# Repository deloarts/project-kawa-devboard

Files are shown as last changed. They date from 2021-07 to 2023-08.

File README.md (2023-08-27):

# Project Kawa Devboard

Documentation for the **Project Kawa Devboard**. This repository contains everything the Wifi-Client requires, including code, circuit design and housing.
















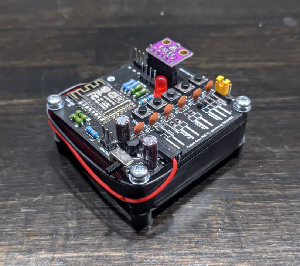
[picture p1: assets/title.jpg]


> ⚠️ The Kawa Devboard is part of my condition monitoring project - Project Kawa - which isn't public. However, this repo is public, because the development board itself works pretty well after a long-term test of now over a year. You can use this board for your own project, if it fits your needs.
> 
> ✏️ The board is compatible with most open source home-automation systems, so feel free to use this board for other appliances than the Project Kawa.
>
> ✏️ In this repo you'll find not only the hardware of the devboard, but also the source. Keep in mind that the code is written for the Project Kawa Server, which isn't public, but feel free to tweak it for your own application.

## Table of contents

- [Project Kawa Devboard](#project-kawa-devboard)
  - [Table of contents](#table-of-contents)
  - [1 Description](#1-description)
  - [2 Usage](#2-usage)
    - [2.1 LED indicator](#21-led-indicator)
    - [2.2 Setup wifi](#22-setup-wifi)
    - [2.3 Reading sensor data](#23-reading-sensor-data)
    - [2.4 Status codes](#24-status-codes)
  - [3 Hardware](#3-hardware)
    - [3.1 Board](#31-board)
    - [3.2 Housing](#32-housing)
  - [4 Environment](#4-environment)
    - [4.1 Used software](#41-used-software)
    - [4.2 VS-Code setup](#42-vs-code-setup)
      - [4.2.1 code-workspace](#421-code-workspace)
      - [4.2.2 arduino.json](#422-arduinojson)
      - [4.2.3 c\_cpp\_properties.json](#423-c_cpp_propertiesjson)
    - [4.3 Eagle libraries](#43-eagle-libraries)
  - [5 Building \& Debugging](#5-building--debugging)
    - [5.1 Initial upload](#51-initial-upload)
    - [5.2 OTA upload](#52-ota-upload)
    - [5.3 Build the firmware](#53-build-the-firmware)
    - [5.4 Build the filesystem](#54-build-the-filesystem)
    - [5.5 Debug](#55-debug)
  - [6 License \& Disclaimer](#6-license--disclaimer)
  - [7 Changelog](#7-changelog)
    - [7.1 Firmware](#71-firmware)
    - [7.2 Filesystem](#72-filesystem)
    - [7.3 PCB](#73-pcb)
    - [7.4 Housing](#74-housing)
  - [8 To Do](#8-to-do)

## 1 Description

**Project Kawa Devboard** is part of the **Project Kawa** environment. This client is designed to test new sensors or new firmware, to debug code or find optimizations in the PCB layout. The latest version may not work without properly -> nightly builds.

This repository contains mostly code that is in development, as well as hardware-design that might only work under special conditions or differ from this documentation. This is not an out-of-the-box solution and requires some knowledge in a variety of fields. If you don't have an education in the field of electronics you should not proceed with this project, you might harm yourself or create damage by the risk of fire. Further you should be comfortable working with VS Code Workspaces.

Please note: All paths and settings are described for Windows. Will be updated in the future.

## 2 Usage

**This requires a working build of the firmware and filesystem already flashed to the chip, see [Initial Upload](#51-initial-upload)**. Please note: The description can differ from the actual process, depending on the development state of this device.

### 2.1 LED indicator

There are different kinds of LED-states to indicate the device's status:

- Short, almost unnoticeable blink: Wakeup from deepsleep, running normal cycle
- Rapid blinking 25 times: Wifi is not setup (this should happen after the initial upload)
- Rapid blinking 2 times: Changes have been written to the config
- On-Off every one second: Wifi-setup is running, hotspot is open

### 2.2 Setup wifi

The device needs to connect to your local network via 2.4GHz wifi. To setup your network's credentials you need to

- press and hold **BUTTON 1**
- click the **RESET** button
- the device opens a hotspot called **kawa setup**
- connect any wifi-enabled device to it
- enter your network-credentials
- select the connected sensor
- select the sleep interval (shorter intervals should only be used for testing and debugging)
- reset the controller afterwards

Now your *Kawa Devboard* is ready for use. As soon as the device connects to your wifi it will automatically connect to the server by its own, assuming that the server is running.

Note: The captive portal may not work properly, if so try:

- Use another device
- Click **yes** if your device asks you to stay connected (happens when the device notices, that no internet connection is available)
- Refresh the captive portal redirection page (sometimes the script or the stylesheet aren't loaded properly)
- Enter the IP address **1.2.3.4** manually into a browser

### 2.3 Reading sensor data

Once the wifi credentials are set up correct the device starts its main task: reading sensor data. There is no further interaction needed. The data is sent as json, example:

```json
{
  "device": {
    "id": "179309432879183923",
    "boardname": "devboard",
    "firmware_version": "0.1.0",
    "filesystem_version": "0.1.0",
    "mode": "production",
    "sensor_status": true,
    "sensor_name": "BMP280",
    "battery_status": true,
    "battery_value": 3.30,
    "sleep_interval": 3600,
    "connection_time": 7.334,
    "ssid": "the_network_ssid",
    "dbm": -78,
    "quality": 44,
    "hostname": "kawa_179309432879183923",
    "ip_address": "192.168.0.200",
    "mac_address": "00:80:41:ae:fd:7e"
  },
  "data": {
    "temperature": {
      "value": 25.2,
      "unit": "°C"
    },
    "pressure": {
      "value": 989.2,
      "unit": "mBar"
    },
    "altitude": {
      "value": 433,
      "unit": "m"
    },
    "humidity": {
      "value": 44.23,
      "unit": "%"
    }
  }
}
```

The server must answer with status code 201 and a json of the following format:

```json
value = {
    "status": "ok",
    "update_firmware": false,
    "new_firmware": "0.0.0",
    "update_spiffs": false,
    "new_spiffs": "0.0.0"
}
```

Due to the OTA-update functionality the client must know when to update. This is done by toggling the respective keys to **true**. With this the client will instantly download the given new version. The maximum size of the json is 2048 bytes.

### 2.4 Status codes

The devices accepts the following status codes as answer when posting data:

- **201**: data has been added to the database
- **406**: data has not been added to the database
- **500**: server error

## 3 Hardware

The core of this application is a ESP12F SOC by [espressif](https://www.espressif.com/en/products/socs/esp8266).

### 3.1 Board

The board is a two layered pcb, with mostly push-through components. This is due to easier hacking into the system, when something new needs testing without making a new pcb.

A complete bill of material can be found inside the [bom folder](docs/bom/).
For the production files select the latest zip-file inside the boards folder.

**Important note**: There is no deep discharge protection for the battery. Do not use non-protected batteries with this setup!

### 3.2 Housing

The housing is made with a 3D printer, files can be found inside the projects cad folder. More information will be added.

## 4 Environment

### 4.1 Used software

- The firmware is created with [VS Code](https://code.visualstudio.com/download) with the [Arduino-Core](https://www.arduino.cc/en/software) (extension: CTRL+P -> *ext install vscode-arduino*))
- The content of the filesystem is compiled with [mkspiffs](https://github.com/igrr/mkspiffs) and uploaded with [esptool](https://github.com/espressif/esptool).
- The pcb design is done with [Autodesk Eagle 9.6.2](https://www.autodesk.de/products/eagle/free-download), but may be continued with [EasyEDA](https://easyeda.com/) due to a better library-to-production support.

A full list of the used software, including versions, libraries and tools can be found at the top of the [src.ino](code/src/src.ino).

### 4.2 VS-Code setup

#### 4.2.1 code-workspace

Workspace-root is the repository-root. All relative paths are from this directory. Add the repository-root to a new workspace and save this workspace (can be saved inside or outside of the repo).

#### 4.2.2 arduino.json

Stored inside the **.vscode/** folder. This folder does not exist when cloning the repo and should appear automatically after creating the workspace, if not:

- Create it: [command-palette](https://code.visualstudio.com/docs/getstarted/userinterface#_command-palette) -> *Arduino: Initialize*
- Edit it: [command-palette](https://code.visualstudio.com/docs/getstarted/userinterface#_command-palette) -> *Arduino: Board Config*

Take the current board config from the description at the top of the [src file](code/src/src.ino).

Add the following lines to the json-file:

```json
  "sketch": "code\\src\\src.ino",
  "output": "code\\build\\firmware\\latest",
```

For the Arduino-Board-Config see the header-comment of the src-file.

#### 4.2.3 c_cpp_properties.json

Stored inside the **.vscode/** folder, create (or add):

```json
"configurations": [
    {
        "name": "Win32",
        "intelliSenseMode": "gcc-x64",
        "includePath": [
            "${workspaceRoot}\\code\\src\\",
            "${workspaceRoot}\\code\\src\\headers\\**",
            "C:\\Program Files (x86)\\Arduino\\hardware\\arduino\\avr\\cores\\arduino\\**",
            "${env:LOCALAPPDATA}\\Arduino15\\packages\\esp8266\\tools\\**",
            "${env:LOCALAPPDATA}\\Arduino15\\packages\\esp8266\\hardware\\esp8266\\3.0.0\\**",
            "${env:LOCALAPPDATA}\\Arduino15\\packages\\esp8266\\hardware\\esp8266\\3.0.0\\libraries\\**",
            "${env:HOMEPATH}\\Documents\\Arduino\\libraries\\ArduinoJson\\**",
            "${env:HOMEPATH}\\Documents\\Arduino\\libraries\\DallasTemperature\\**",
            "${env:HOMEPATH}\\Documents\\Arduino\\libraries\\OneWire\\**",
            "${env:HOMEPATH}\\Documents\\Arduino\\libraries\\Adafruit_Unified_Sensor\\**",
            "${workspaceRoot}\\code\\assets\\libraries\\Adafruit_BME280_Library\\**"
        ],
        "forcedInclude": [
            "C:\\Program Files (x86)\\Arduino\\hardware\\arduino\\avr\\cores\\arduino\\Arduino.h"
        ],
        "cStandard": "c11",
        "cppStandard": "c++17",
        "defines": []
    }
]
```

Please note: Some include-paths are only valid if you have chosen the standard path when you installed the Arduino-IDE on a Windows computer.

### 4.3 Eagle libraries

Can be found inside the pcb-folder. Must not be added to EAGLE if you don't plan on changing the board.

## 5 Building & Debugging

Tested and released firmware and filesystem versions can be found inside the respective folder

- [Firmware](code/build/firmware/)
- [Filesystem](code/build/filesystem/)

Those firmware-versions with the letter **d** after the version indicator are debug-versions. This means that you can hookup a serial-to-usb chip and get debug messages printed to a serial monitor. Baud-rate is always 115200. Versions without that letter are for production environment, you won't get any messages printed to the serial port.

### 5.1 Initial upload

To flash the firmware and filesystem initially you need to upload both with a usb-to-serial converter (popular method: use a [FTDI232 module](https://ftdichip.com/drivers/)). The upload process requires you to

- press and hold the **UPLOAD** button
- press and release the **RESET** button
- release the **UPLOAD** button as soon as the upload begins
- click the **RESET** button after the upload is done

The initial firmware can be uploaded with the command-palette -> *Arduino: Upload*.

The initial filesystem can be uploaded with *[SPIFFS for Arduino](https://github.com/esp8266/arduino-esp8266fs-plugin/releases)*.

### 5.2 OTA upload

New firmware/filesystem will be automatically installed by the **Project Kawa Server**. With every post-request (device -> server) the server answers with the newest firmware/filesystem version. If the current one is older the device will download and install the latest one. This process is called OTA.

This requires a working initial firmware to be flashed onto the device, see [Initial Setup](#51-initial-upload).

In order for the OTA to work you then have to copy the newest firmware/filesystem into the server's bin-directory. Please refer to the server's documentation for the correct filename or use the [test server](code/dev/test_server/test_server.py) from the **/dev** folder. The test server returns only the file set at the top-section. Do not use the test server in a production environment.

### 5.3 Build the firmware

The firmware is built when the src-file is compiled without any errors (command-palette -> *Arduino: Verify*). The binary file is then stored inside the latest-folder of build-directory, as instructed in the *4.2.2 arduino.json*.

### 5.4 Build the filesystem

Currently in testing.

### 5.5 Debug

To debug the firmware uncomment the **#define DEBUG** statement inside the [definitions.h](code/src/headers/definitions.h) file. Connect a serial-to-usb device to the RX-TX pins of the device, upload the changed code and open the serial monitor with 115200 baud rate.

To debug the captive portal content (files inside the [data folder](code/src/data/)) you can use any static file server. Tip: Run Python's builtin module **python -m http.server** inside the data folder.

## 6 License & Disclaimer

MIT.

All content on this repository is provided **as is**. None of these components have been tested or certified. The use of this content is **at your own risk**.

## 7 Changelog

### 7.1 Firmware

**v0.1.2**: Updated libraries.  
**v0.1.1**: Updated battery range.  
**v0.1.0**: Added location and updated api.  
**v0.0.0**: Creation.

### 7.2 Filesystem

**v0.1.0**: Added location.  
**v0.0.0**: Creation.

### 7.3 PCB

**Rev0**: Creation.

### 7.4 Housing

**Rev1**: Updated for FFF.  
**Rev0**: Creation.

## 8 To Do

- [ ] Fix: Wifi settings are overwritten when filesystem gets updated.
- [ ] Fix: Slow/laggy captive portal.
- [ ] Fix: Replace FS with LittleFS.
- [ ] Fix: Allow only one client at the captive portal.
- [ ] Replace: Change frontend to Vue CLI.
- [ ] Add: Switch sensor.
- [ ] Add: Air quality sensor.
- [ ] Add: Rain sensor (amount and state).
- [ ] Add: Moisture sensor.
- [ ] Add: Analog input (may require additional hardware).
- [ ] Test: Relay output (requires additional hardware).
- [ ] Test: LED controller (requires additional hardware).
- [ ] Test: Deep discharge protection (requires additional hardware).

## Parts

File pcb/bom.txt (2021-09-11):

Qty Value                           Device                          Package                  Parts                           Description                          
1                                   ESP-12                          ESP-12                   X1                                                                   
1                                   LEDSFH480                       SFH480                   LED1                            LED                                  
1                                   MA03-1                          MA03-1                   VOLTAGE                         PIN HEADER                           
1                                   MA06-1                          MA06-1                   BME280                          PIN HEADER                           
4                                   PINHD-1X2/90                    1X02/90                  JP_BTN1, JP_BTN2, JP_BTN3, PWR  PIN HEADER                           
2                                   PINHD-1X3                       1X03                     SELECT1, UART                   PIN HEADER                           
1                                   PINHD-1X3/90                    1X03/90                  ONEWIRE                         PIN HEADER                           
1                                   PINHD-1X4                       1X04                     I2C                             PIN HEADER                           
6   100nF 50V                       C2,5-3                          C2.5-3                   C3, C4, C5, C6, C7, C8          CAPACITOR                            
4   10K                             R-EU_0204/7                     0204/7                   R1, R2, R3, R9                  RESISTOR, European symbol            
2   10uF 100V                       CPOL-EUE2-5                     E2-5                     C1, C2                          POLARIZED CAPACITOR, European symbol 
1   390                             R-EU_0204/7                     0204/7                   R8                              RESISTOR, European symbol            
1   3K9                             R-EU_0204/7                     0204/7                   R7                              RESISTOR, European symbol            
2   4K7                             R-EU_0204/7                     0204/7                   R4, R5                          RESISTOR, European symbol            
1   MCP1700-3302E/TO                MCP1700-3302E/TO                TO127P254X495-3          U1                              IC LDO REG 250MA 5.0V Check prices   
5   MOMENTARY-SWITCH-SPST-PTH-6.0MM MOMENTARY-SWITCH-SPST-PTH-6.0MM TACTILE_SWITCH_PTH_6.0MM BTN1, BTN2, BTN3, RESET, UPLOAD Momentary Switch (Pushbutton) - SPST 
1   SK-12D07                        SK-12D07                        SK12SWITCH               SW1

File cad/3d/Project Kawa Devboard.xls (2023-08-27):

Tuesday, 12 April 2022 17:17:47
Stückliste: Project Kawa Devboard
Menge | Teilenummer | Typ | Nomenklatur | Überarbeitung
1 | A01 Housing | Baugruppe
1 | A02 PCB | Baugruppe | PCB Component
Stückliste: A01 Housing
Menge | Teilenummer | Typ | Nomenklatur | Überarbeitung
1 | A01-P01 | Teil
1 | A01-P02 | Teil
1 | A01-P03 | Teil
1 | A01-P04 | Teil
1 | A01-P05 | Teil
2 | Battery spring - Form 1 - FXFC | Teil
1 | Battery spring - Form 2 - FXFC | Teil
1 | Battery spring - Form 3 - FXFC | Teil
4 | Washer M3 - DIN EN ISO 7090-3-200HV - Standards | Teil
4 | Hexagon Head Screw M3x25 - ISO 4762-M3x25 8.8 - Standards | Teil
4 | Countersunk Screw M3x6 - ISO 10642-M3x6 8.8 - Standards | Teil
4 | Countersunk Screw M3x10 - ISO 10642-M3x10 8.8 - Standards | Teil
4 | Countersunk Screw M3x16 - ISO 10642-M3x16 8.8 - Standards | Teil
4 | Rubber Bushing - 26103-00800855 - Norelem | Teil
10 | Threaded insert M3 x 5.2 - 071M3 - KVT | Teil | _KVT 071M3
Stückliste: A02 PCB
Menge | Teilenummer | Typ | Nomenklatur | Überarbeitung
1 | A02-P01 | Teil | Board
4 | Nut M3 - ISO 4032-M3-10 - Standards | Teil
1 | IC ESP-12F - C82891 - LCSC | Teil
1 | Voltage Regulator MCP1700-3302E_TO - C511277 - LCSC | Teil | TO127P254X495-3
6 | Capacitor 100nF 50V - C377838 - LCSC | Teil | C2.5-3
8 | Resistor 3K9 250mW - C274457 - LCSC | Teil | 0204/7
2 | Capacitor 10uF 100V - C240350 - LCSC | Teil | E2-5
5 | Tactile Switch SPST 4.5x4.5x4.3 - C620333 - LCSC | Teil | Tact Switch
1 | Switch SK-12D07 - C521448 - LCSC | Teil | SK12SWITCH
3 | Pin Header 03-1 - C2894926 - LCSC | Teil | 1X03
1 | Pin Header 04-1 - C2894927 - LCSC | Teil | 1X04
1 | Pin Header 06-1 - C2894929 - LCSC | Teil | MA06-1
4 | Pin Header 02-1_90 - C2894944 - LCSC | Teil | 1X02/90
1 | Pin Header 03-1_90 - C2894945 - LCSC | Teil | 1X03/90
1 | SFH480 | Teil | SFH480
Wiederholung von: Project Kawa Devboard
Verschiedene Teile: 30
Teile gesamt: 83
Menge | Teilenummer
1 | A01-P01
1 | A01-P02
1 | A01-P03
1 | A01-P04
1 | A01-P05
2 | Battery spring - Form 1 - FXFC
1 | Battery spring - Form 2 - FXFC
1 | Battery spring - Form 3 - FXFC
4 | Washer M3 - DIN EN ISO 7090-3-200HV - Standards
4 | Hexagon Head Screw M3x25 - ISO 4762-M3x25 8.8 - Standards
4 | Countersunk Screw M3x6 - ISO 10642-M3x6 8.8 - Standards
4 | Countersunk Screw M3x10 - ISO 10642-M3x10 8.8 - Standards
4 | Countersunk Screw M3x16 - ISO 10642-M3x16 8.8 - Standards
4 | Rubber Bushing - 26103-00800855 - Norelem
10 | Threaded insert M3 x 5.2 - 071M3 - KVT
1 | A02-P01
4 | Nut M3 - ISO 4032-M3-10 - Standards
1 | IC ESP-12F - C82891 - LCSC
1 | Voltage Regulator MCP1700-3302E_TO - C511277 - LCSC
6 | Capacitor 100nF 50V - C377838 - LCSC
8 | Resistor 3K9 250mW - C274457 - LCSC
2 | Capacitor 10uF 100V - C240350 - LCSC
5 | Tactile Switch SPST 4.5x4.5x4.3 - C620333 - LCSC
1 | Switch SK-12D07 - C521448 - LCSC
3 | Pin Header 03-1 - C2894926 - LCSC
1 | Pin Header 04-1 - C2894927 - LCSC
1 | Pin Header 06-1 - C2894929 - LCSC
4 | Pin Header 02-1_90 - C2894944 - LCSC
1 | Pin Header 03-1_90 - C2894945 - LCSC
1 | SFH480

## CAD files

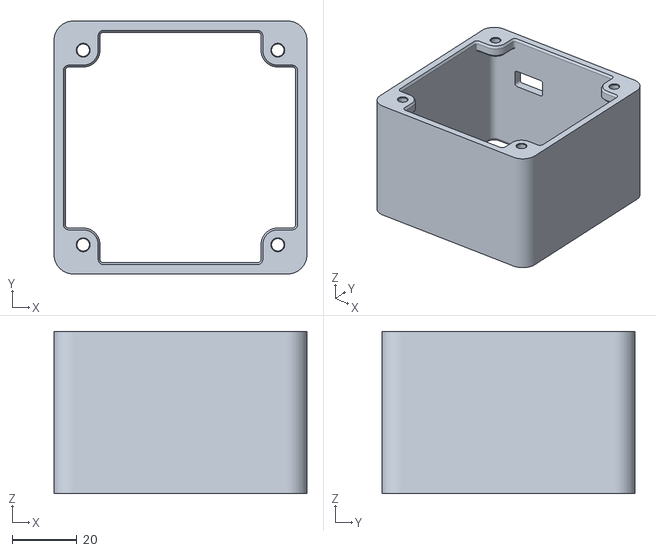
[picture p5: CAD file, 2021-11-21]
cad/cam/A01-P02.stl
78.0 x 78.0 x 50.0

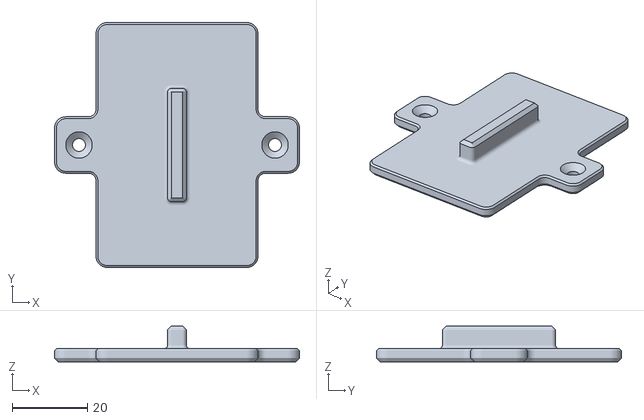
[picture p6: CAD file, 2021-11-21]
cad/cam/A01-P05.stl
65.0 x 65.0 x 9.50

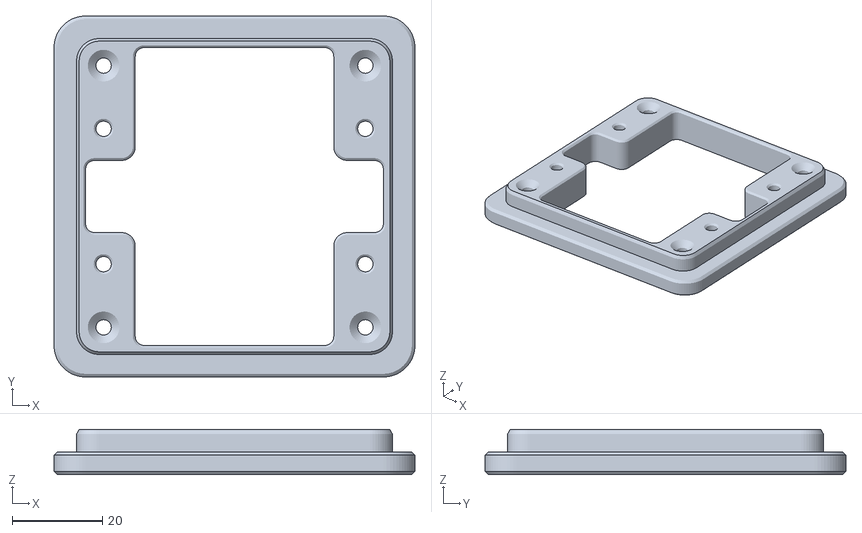
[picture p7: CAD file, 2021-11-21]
cad/cam/A01-P03.stl
80.0 x 80.0 x 10.0

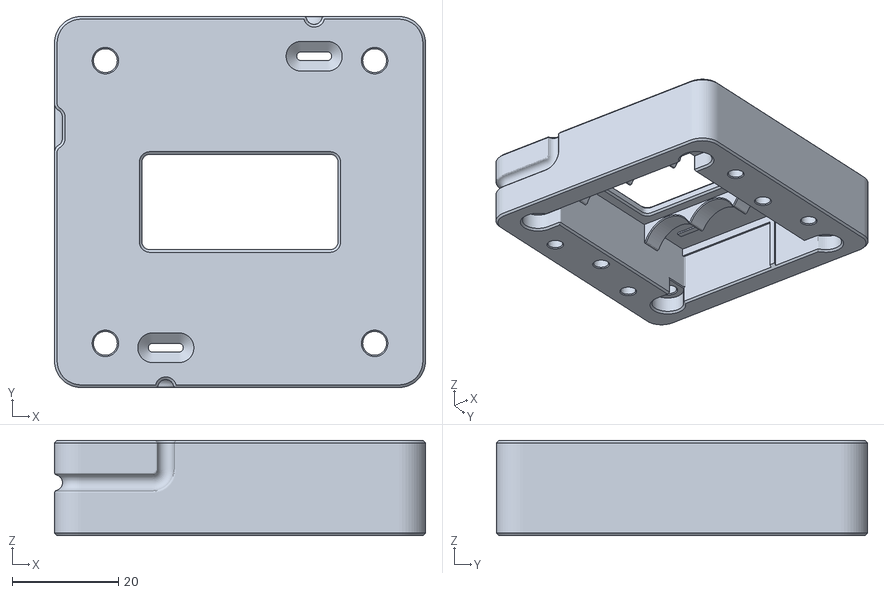
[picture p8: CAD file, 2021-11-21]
cad/cam/A01-P01.stl
70.0 x 70.0 x 18.0

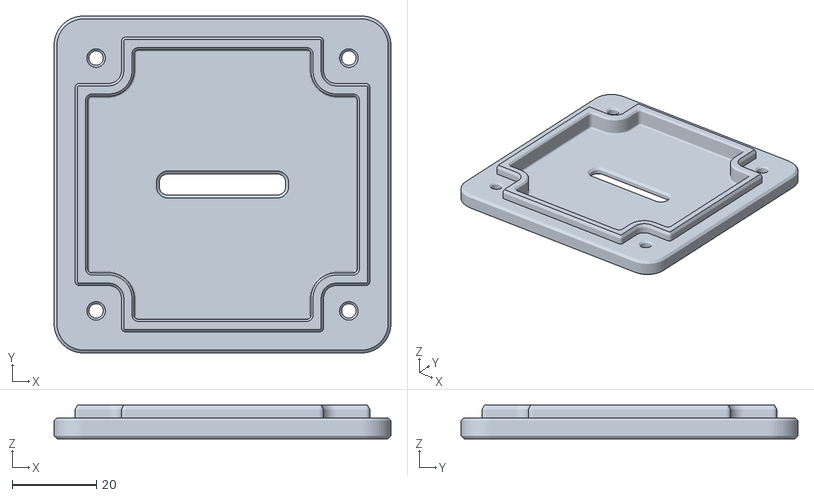
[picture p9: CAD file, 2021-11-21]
cad/cam/A01-P04.stl
80.0 x 80.0 x 8.00

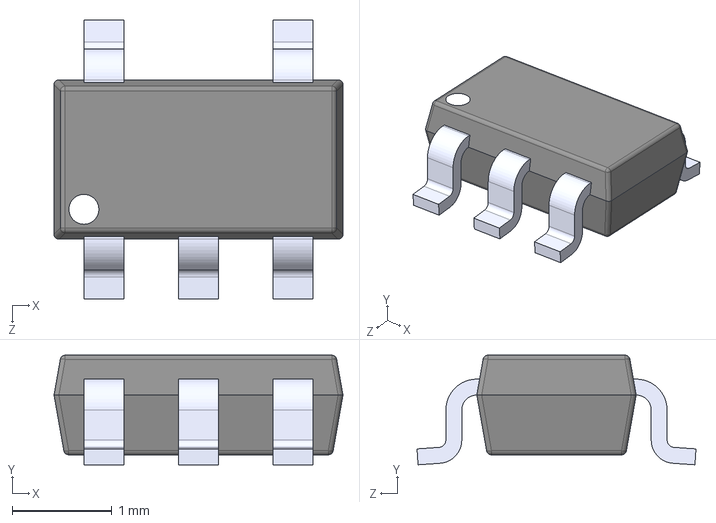
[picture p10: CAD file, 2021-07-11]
pcb/lbr/TPS78233DDCT.STEP
2.90 x 1.10 x 2.80 mm

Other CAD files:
cad/3d/A01 Housing/A01 Housing.CATProduct
cad/3d/A01 Housing/A01-P01.CATPart
cad/3d/A01 Housing/A01-P02.CATPart
cad/3d/A01 Housing/A01-P03.CATPart
cad/3d/A01 Housing/A01-P04.CATPart
cad/3d/A01 Housing/A01-P05.CATPart
cad/3d/A02 PCB/A02 PCB.CATProduct
cad/3d/A02 PCB/A02-P01.CATPart
cad/3d/Project Kawa Devboard.CATProduct
cad/3d/assets/Axissystem.CATPart
cad/3d/assets/Electronics/Capacitor 100nF 50V - C377838 - LCSC.CATPart
cad/3d/assets/Electronics/Capacitor 10uF 100V - C240350 - LCSC.CATPart
cad/3d/assets/Electronics/IC ESP-12F - C82891 - LCSC.CATPart
cad/3d/assets/Electronics/Pin Header 02-1_90 - C2894944 - LCSC.CATPart
cad/3d/assets/Electronics/Pin Header 03-1 - C2894926 - LCSC.CATPart
cad/3d/assets/Electronics/Pin Header 03-1_90 - C2894945 - LCSC.CATPart
cad/3d/assets/Electronics/Pin Header 04-1 - C2894927 - LCSC.CATPart
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

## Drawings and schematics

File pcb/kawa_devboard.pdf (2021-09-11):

GND | 10K 100nF 50V | 100nF 50V

A

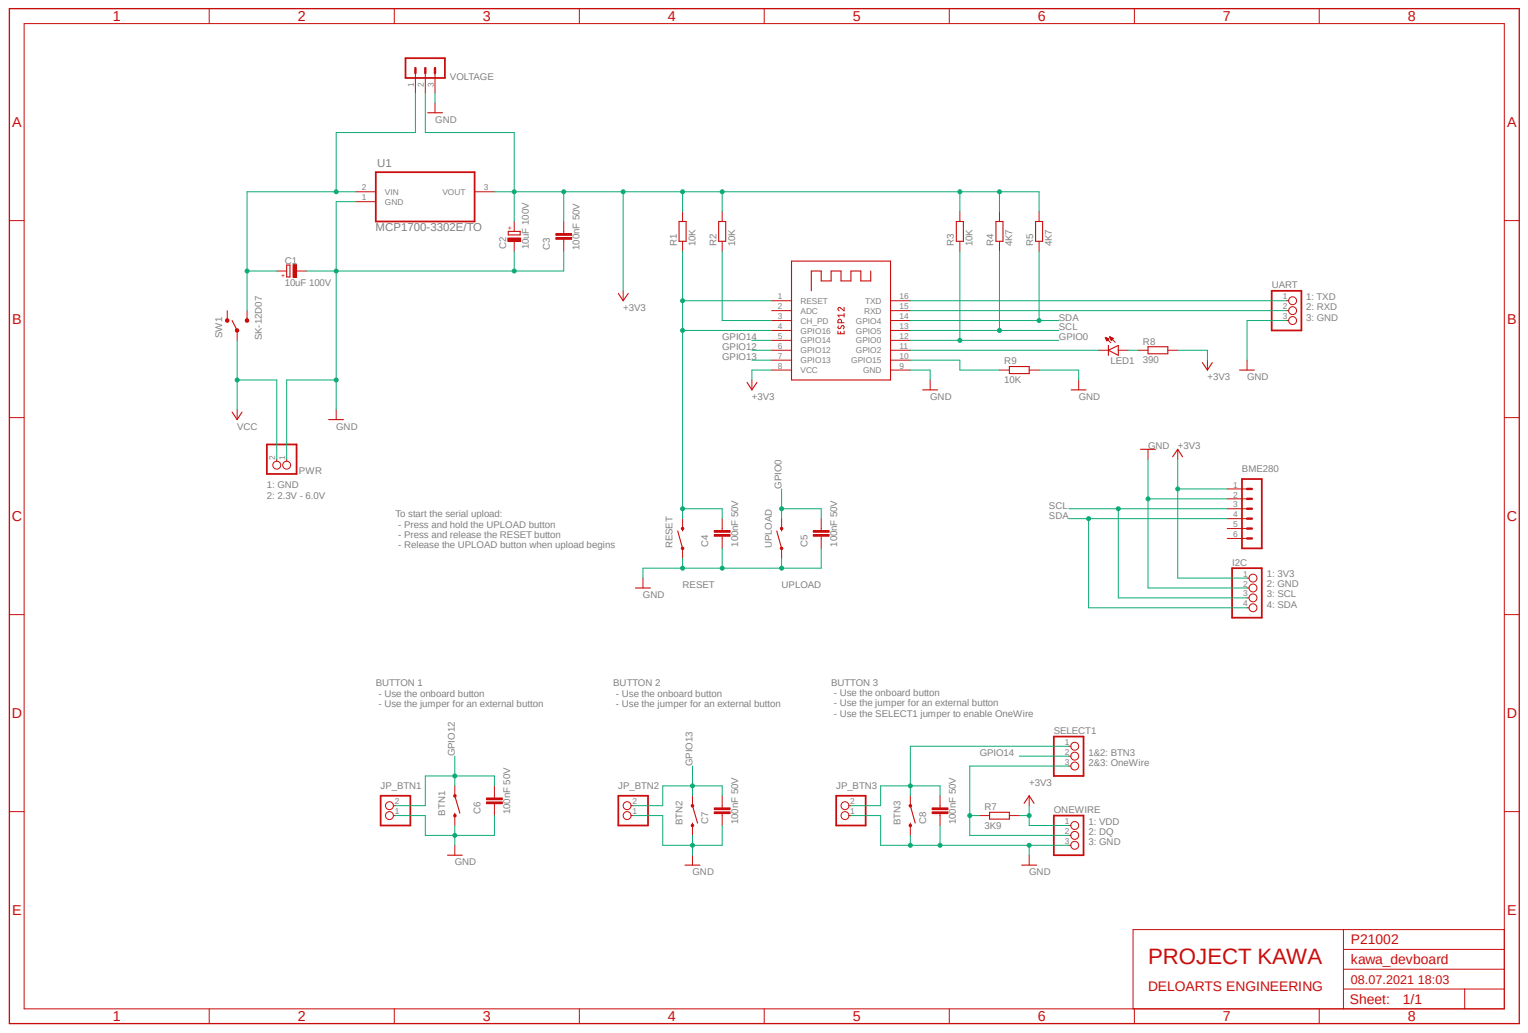
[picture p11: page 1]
1: TXD 2: RXD 3: GND; RESET; UPLOAD; 1: 3V3 2: GND 3: SCL 4: SDA; 1: GND 2: 2.3V - 6.0V; 1: VDD 2: DQ 3: GND; 1&2: BTN3 2&3: OneWire; - Release the UPLOAD button when upload begins ¹⁰⁰nF 50V; GND; GND ⁴K⁷; GND +3V3; MCP1700-3302E/TO; +3V3 SK⁻¹²D⁰⁷; VCC; R² RESET; C⁵ BTN¹; GPIO16 4 GPIO14 5 GPIO12 6 GPIO13 7; VCC 8; GPIO15; 10 GPIO2; 11 GPIO0; 12 GPIO5; 13 GPIO4; 14 RXD; 15 TXD; LED1; R9 R³ BTN²; BTN³; VIN 2 GND 1; VOUT; BME280; UART 2; PWR SW¹; SELECT1; JP_BTN3; JP_BTN2; JP_BTN1; ONEWIRE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

RESET 1
ADC 2 CH_PD 3

To start the serial upload:
- Press and hold the UPLOAD button
- Press and release the RESET button

BUTTON 1
- Use the onboard button
- Use the jumper for an external button

BUTTON 2

BUTTON 3
- Use the SELECT1 jumper to enable OneWire

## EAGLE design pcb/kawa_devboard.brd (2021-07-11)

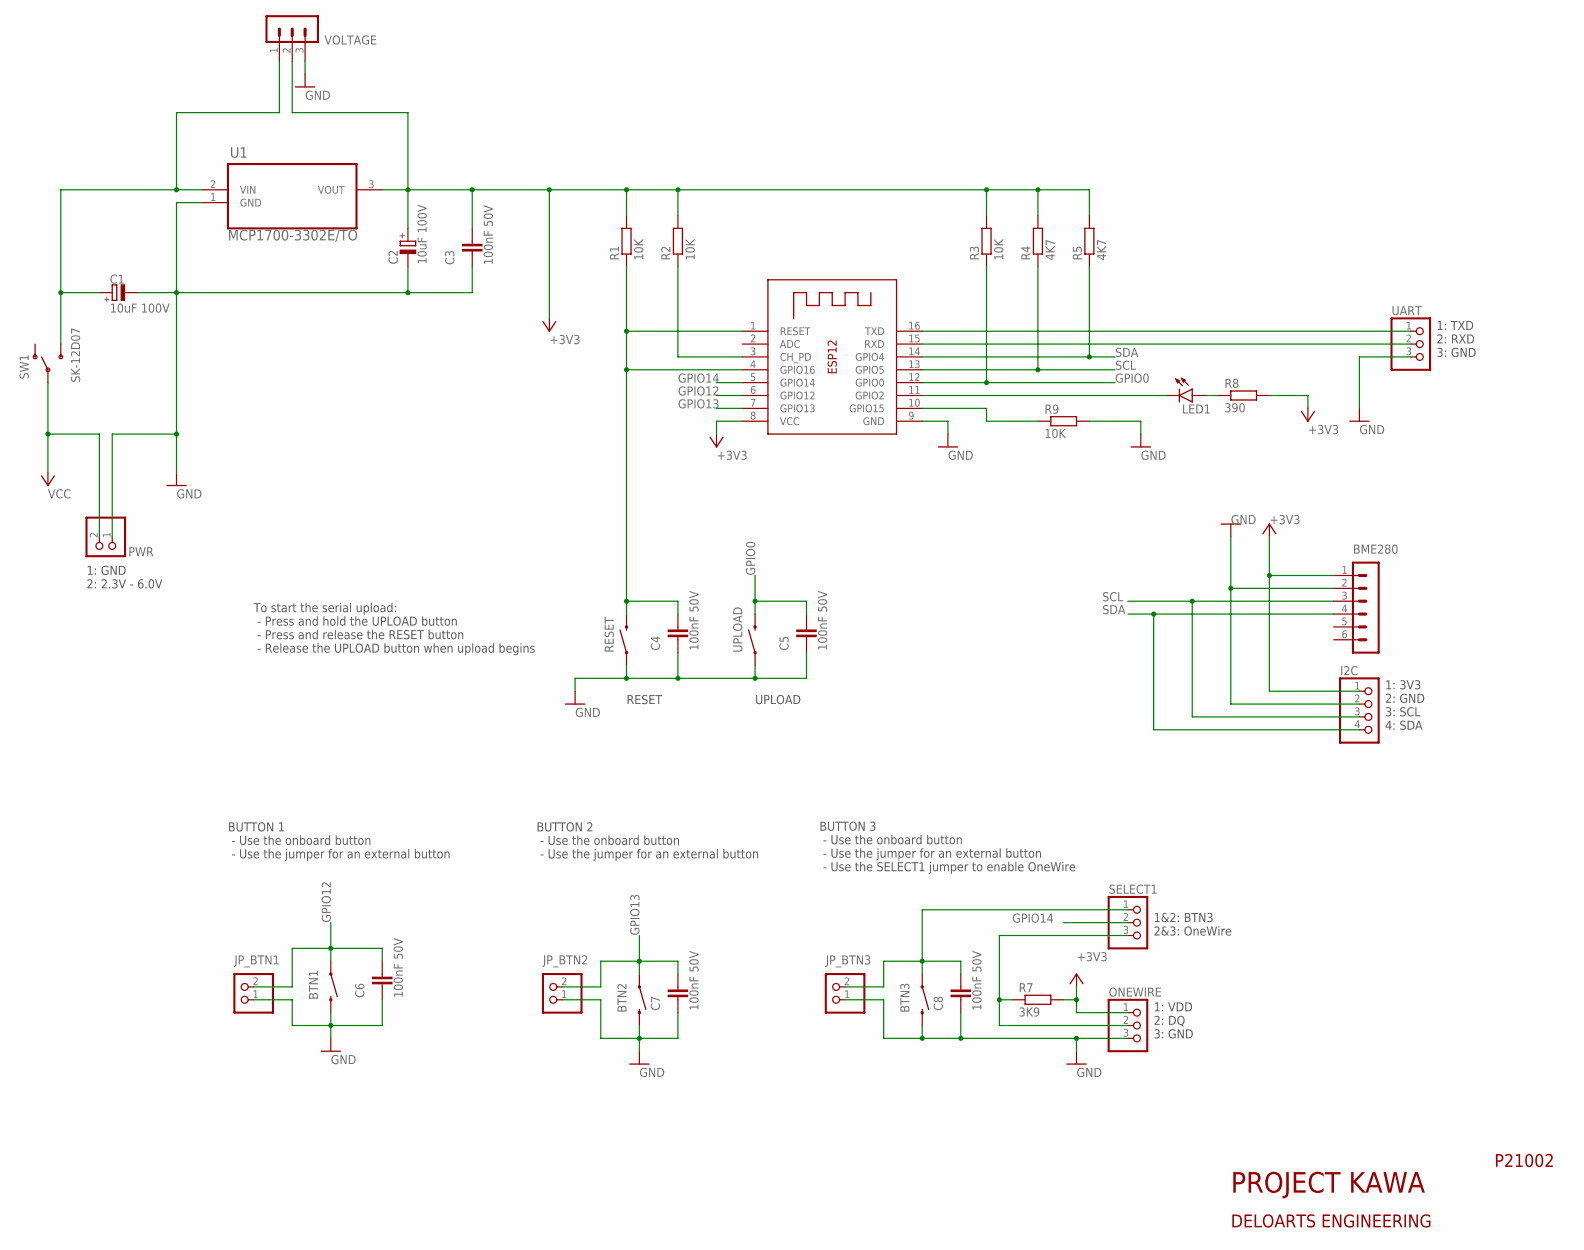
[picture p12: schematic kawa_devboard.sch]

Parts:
BME280: MA06-1
BTN1, BTN2, BTN3: MOMENTARY-SWITCH-SPST-PTH-6.0MM; TACTILE_SWITCH_PTH_6.0MM
C1, C2: 10uF 100V; E2-5
C3, C4, C5, C6, C7, C8: 100nF 50V; C2.5-3
I2C: PINHD-1X4; 1X04
JP_BTN1, JP_BTN2, JP_BTN3: PINHD-1X2/90; 1X02/90
LED1: LEDSFH480; SFH480
ONEWIRE: PINHD-1X3/90; 1X03/90
PWR: PINHD-1X2/90; 1X02/90
R1, R2, R3, R9: 10K; 0204/7
R4, R5: 4K7; 0204/7
R7: 3K9; 0204/7
R8: 390; 0204/7
RESET: MOMENTARY-SWITCH-SPST-PTH-6.0MM; TACTILE_SWITCH_PTH_6.0MM
SELECT1: PINHD-1X3; 1X03
SW1: SK-12D07; SK12SWITCH
U1: MCP1700-3302E/TO; TO127P254X495-3
UART: PINHD-1X3; 1X03
UPLOAD: MOMENTARY-SWITCH-SPST-PTH-6.0MM; TACTILE_SWITCH_PTH_6.0MM
VOLTAGE: MA03-1
X1: ESP-12

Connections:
+3V3: BME280.1, C2.+, C3.1, I2C.1, ONEWIRE.1, R1.2, R2.2, R3.2, R4.2, R5.2, R7.2, R8.2, U1.3 (VOUT), VOLTAGE.2, X1.8 (VCC)
BTN3: BTN3.1, C8.1, JP_BTN3.2, SELECT1.1
CH_PD: R2.1, X1.3 (CH_PD)
DQ: ONEWIRE.2, R7.1, SELECT1.3
GND: BME280.2, BTN1.3 (2), BTN2.3 (2), BTN3.3 (2), C1.-, C2.-, C3.2, C4.2, C5.2, C6.2, C7.2, C8.2, I2C.2, JP_BTN1.1, JP_BTN2.1, JP_BTN3.1, ONEWIRE.3, PWR.1, R9.2, RESET.1, U1.1 (GND), UART.3, UPLOAD.1, VOLTAGE.3, X1.9 (GND)
GPIO0: C5.1, R3.1, UPLOAD.3 (2), X1.12 (GPIO0)
GPIO2: LED1.K (C), X1.11 (GPIO2)
GPIO12: BTN1.1, C6.1, JP_BTN1.2, X1.6 (GPIO12)
GPIO13: BTN2.1, C7.1, JP_BTN2.2, X1.7 (GPIO13)
GPIO14: SELECT1.2, X1.5 (GPIO14)
GPIO15: R9.1, X1.10 (GPIO15)
LED1: LED1.A, R8.1
RST: C4.1, R1.1, RESET.3 (2), X1.1 (RESET), X1.4 (GPIO16)
RXD: UART.2, X1.15 (RXD)
SCL: BME280.3, I2C.3, R4.1, X1.13 (GPIO5)
SDA: BME280.4, I2C.4, R5.1, X1.14 (GPIO4)
TXD: UART.1, X1.16 (TXD)
VCC: PWR.2, SW1.P2
VIN: C1.+, SW1.IN (S), U1.2 (VIN), VOLTAGE.1

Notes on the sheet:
1: TXD 2: RXD 3: GND
RESET
UPLOAD
BUTTON 1 - Use the onboard button - Use the jumper for an external button
BUTTON 2 - Use the onboard button - Use the jumper for an external button
BUTTON 3 - Use the onboard button - Use the jumper for an external button - Use the SELECT1 jumper to enable OneWire
1: 3V3 2: GND 3: SCL 4: SDA
1: GND 2: 2.3V - 6.0V
1: VDD 2: DQ 3: GND
1&2: BTN3 2&3: OneWire
To start the serial upload: - Press and hold the UPLOAD button - Press and release the RESET button - Release the UPLOAD button when upload begins
P21002
PROJECT KAWA
DELOARTS ENGINEERING

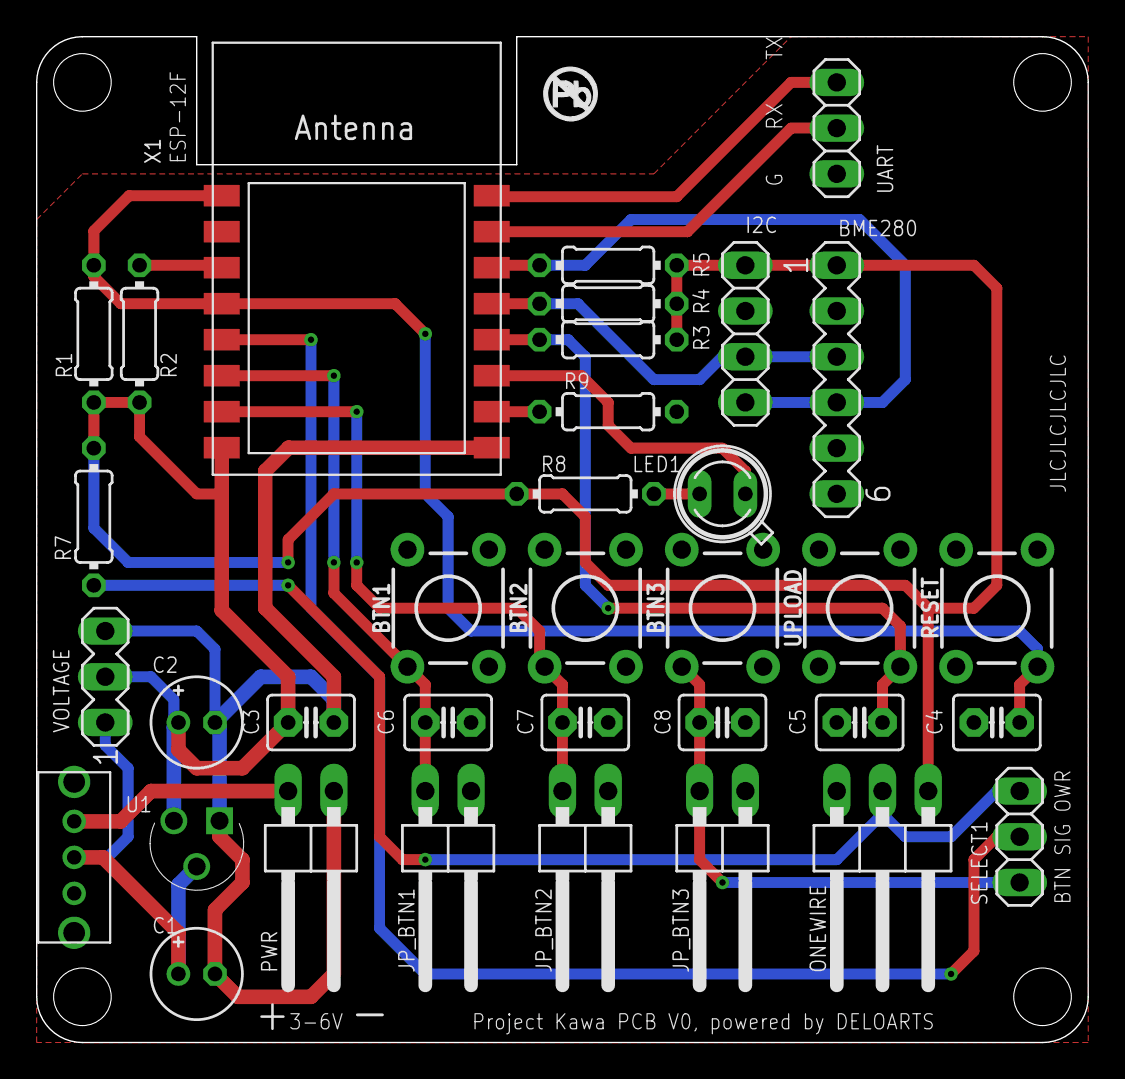
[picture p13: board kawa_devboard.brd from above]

Board: 2 copper layers, 58.4 x 55.9 mm, 36 parts (0 on the bottom side), 19 nets.

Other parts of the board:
U$1: NO_PB_LOGO_0.120

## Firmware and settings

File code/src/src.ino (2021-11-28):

/*
    Project Kawa Client

    Date        2021.07.11
    Author      Philip Delorenzo
    License     None
    Repo        https://github.com/deloarts/project-kawa-devboard

- - - - - - - - - - - - - - - - - - - - - - - - - - - - - - - - - - - - - - - - - - - - - - -
  DESCRIPTION
- - - - - - - - - - - - - - - - - - - - - - - - - - - - - - - - - - - - - - - - - - - - - - -
    See README.md

- - - - - - - - - - - - - - - - - - - - - - - - - - - - - - - - - - - - - - - - - - - - - - -
  IDE / SOFTWARE
- - - - - - - - - - - - - - - - - - - - - - - - - - - - - - - - - - - - - - - - - - - - - - -
	SOFTWARE                VERSION         LINKS
	VS Code                 current         https://code.visualstudio.com/download
	Arduino IDE             1.8.15          https://www.arduino.cc/download_handler.php?f=/arduino-1.8.15-windows.exe
    SPIFFS FS for Arduino   0.5.0           https://github.com/esp8266/arduino-esp8266fs-plugin/releases
	Arduino for VS Code     0.3.0           https://marketplace.visualstudio.com/items?itemName=vsciot-vscode.vscode-arduino

	LIBRARY                 VERSION         INSTALLATION VIA            LINKS
	esp8266                 3.0.0           Arduino Board Manager       http://arduino.esp8266.com/stable/package_esp8266com_index.json
    ArduinoJson             6.18.5          Arduino Library Manager     https://arduinojson.org/?utm_source=meta&utm_medium=library.properties
	OneWire                 2.3.6           Arduino Library Manager     https://www.pjrc.com/teensy/td_libs_OneWire.html
    DallasTemperature       3.9.0           Arduino Library Manager     https://github.com/milesburton/Arduino-Temperature-Control-Library
    Unified Sensor          1.1.4           Arduino Library Manager     https://github.com/adafruit/Adafruit_Sensor
    Adafruit_BME280         2.1.4 (mod)     Assets Folder               h̶t̶t̶p̶s̶:̶/̶/̶g̶i̶t̶h̶u̶b̶.̶c̶o̶m̶/̶a̶d̶a̶f̶r̶u̶i̶t̶/̶A̶d̶a̶f̶r̶u̶i̶t̶_̶B̶M̶E̶2̶8̶0̶_̶L̶i̶b̶r̶a̶r̶y̶

    Important note:
    Since the Adafruit_BMP280 library doesn't support sleep-mode it has been modified and
    stored in the assets folder. Keep that in mind when adding it to the c_cpp_properties.json.

- - - - - - - - - - - - - - - - - - - - - - - - - - - - - - - - - - - - - - - - - - - - - - -
  HARDWARE
- - - - - - - - - - - - - - - - - - - - - - - - - - - - - - - - - - - - - - - - - - - - - - -
    See the schematics PDF.

- - - - - - - - - - - - - - - - - - - - - - - - - - - - - - - - - - - - - - - - - - - - - - -
  BOARD Config
- - - - - - - - - - - - - - - - - - - - - - - - - - - - - - - - - - - - - - - - - - - - - - -
	Board:              Generic ESP8266 Module (esp8266)
	CPU Frequency:      160 MHz
    MMU:                32KB cache + 32KB IRAM
    Flash Frequency:    40 MHz
    Flash Mode:         DOUT
	Flash Size:         4M (FS:3MB, OTA:~512KB)
	Upload Speed:       115200
	Core Debug Level:   None

- - - - - - - - - - - - - - - - - - - - - - - - - - - - - - - - - - - - - - - - - - - - - - -
  IMPORTANT NOTES
- - - - - - - - - - - - - - - - - - - - - - - - - - - - - - - - - - - - - - - - - - - - - - -   
    Don't forget to upload the sketch data folder to the SPIFFS.
    Currently 'FS' is in use, but it's deprecated and will be replaced by
    'LittleFS'. Should be changed sometime.
    
    To upload the code you need to:
     - Press and hold the UPLOAD button
     - Press and release the RESET button
     - Release the UPLOAD button as soon as the process starts
     - Press the RESET button after the upload is done

    After uploading (serial) you need to hard reset the chip, otherwise the 
    ESP.reset function will fail.

    Don't forget to setup the include-paths in the c_cpp_properties.json
    
	Don't forget to setup the build path and the working file in the arduino.json

*/

#define ARDUINOJSON_ENABLE_ARDUINO_STRING 1

#include <Arduino.h>
#include <ArduinoJson.h>
#include <DNSServer.h>
#include <ESP8266HTTPClient.h>
#include <ESP8266WiFi.h>
#include <ESP8266WebServer.h>
#include <ESP8266mDNS.h>
#include <ESP8266httpUpdate.h>
#include <FS.h> // SPIFFS is depricated, see https://arduino-esp8266.readthedocs.io/en/latest/filesystem.html#spiffs-deprecation-warning
// #include <LittleFS.h>

extern "C"
{
    #include "user_interface.h"    
    
    #include "headers/definitions.h"
    #include "headers/globals.h"
    #include "headers/util.h"
    #include "headers/sensor.h"
    #include "headers/power.h"
    #include "headers/filesystem.h"
    #include "headers/captive_portal.h"
    #include "headers/update.h"
}

ADC_MODE(ADC_VCC);

#pragma region DAILY BUSINESS

bool connect_wifi()
{
    serial_info_ln("Connecting to wifi... ");
    if (cfg.ssid[0] == 0)
    {
        serial_error_ln("Wifi credentials not set.");
        return false;
    }
    else
    {
        char hostname[100];
        get_hostname().toCharArray(hostname, sizeof(hostname));

        connection_time = millis();
        wifi_station_set_hostname(hostname);
        WiFi.begin(cfg.ssid, cfg.password);
        int result = WiFi.waitForConnectResult();
        connection_time = millis() - connection_time;

        serial_info_ln("Connected to Wifi:");
        serial_enum_ln("SSID:     " + String(cfg.ssid));
        serial_enum_ln("Password: " + String(cfg.password[0]) + "***");
        serial_enum_ln("Server:   " + String(cfg.address));
        serial_enum_ln("Port:     " + String(cfg.port));
        return true;
    }
}

void post_data()
{
    int8_t dbm = WiFi.RSSI();
    long response = 0;
    byte attempt = 0;
    String url = "http://" + String(cfg.address) + ":" + String(cfg.port) + api_post_data;

    char json_output[2048];
    DynamicJsonDocument doc(2048);
    JsonObject j_device  = doc.createNestedObject("device");
    JsonObject j_data  = doc.createNestedObject("data");

    JsonObject j_temperature = j_data.createNestedObject("temperature");
    JsonObject j_pressure = j_data.createNestedObject("pressure");
    JsonObject j_altitude = j_data.createNestedObject("altitude");
    JsonObject j_humidity = j_data.createNestedObject("humidity");

    j_device["device_id"] = get_device_id();
    j_device["location"] = cfg.location;
    j_device["boardname"] = board_name;
    j_device["firmware_version"] = firmware_version;
    j_device["filesystem_version"] = filesystem_version;
    j_device["mode"] = software_state;
    j_device["sensor_status"] = sensor_ok;
    j_device["sensor_name"] = cfg.sensor;
    j_device["battery_available"] = battery_available;
    j_device["battery_max"] = battery_full;
    j_device["battery_min"] = battery_too_low;
    j_device["battery_status"] = voltage.ok;
    j_device["battery_value"] = voltage.value;
    j_device["sleep_interval"] = cfg.interval * 60;
    j_device["connection_time"] = connection_time;
    j_device["ssid"] = cfg.ssid;
    j_device["dbm"] = dbm;
    j_device["quality"] = get_quality_from_dbm(dbm);
    j_device["hostname"] = get_hostname();
    j_device["ip_address"] = get_ip_address();
    j_device["mac_address"] = get_mac_address();

    if (temperature.available)
    {
        j_temperature["value"] = temperature.value;
        j_temperature["unit"] = temperature.unit;
    }
    if (pressure.available)
    {
        j_pressure["value"] = pressure.value;
        j_pressure["unit"] = pressure.unit;
    }
    if (altitude.available)
    {
        j_altitude["value"] = altitude.value;
        j_altitude["unit"] = altitude.unit;
    }
    if (humidity.available)
    {
        j_humidity["value"] = humidity.value;
        j_humidity["unit"] = humidity.unit;
    }

    serial_info("Serializing json: ");
    serializeJson(doc, json_output);
    serial_print_ln("OK");
    serial_enum_ln(json_output);
    
    http.begin(client, url);
	http.addHeader("Content-Type", "application/json");
	http.addHeader("Access-Control-Allow-Methods", "POST");

	serial_info_ln("Sending POST request to " + String(url) + " ...");
    while (response != 201 && response != 406 && response != 500)
    {
        response = http.POST(json_output);
        switch (response)
        {
            case 201:
                serial_info_ln("OK at attempt " + String(attempt));
                break;
            case 406:
                serial_info_ln("Failed at attempt " + String(attempt) + " with status code 406: " + http.getString());
                return;
            case 500:
                serial_info_ln("Failed at attempt " + String(attempt) + " with status code 500: " + http.getString());
                return;
            default:
                if (attempt > max_retries_post)
                {
                    serial_error_ln("Aborted because of too many attempts. Server did not answer.");
                    return;
                }
                else
                {
                    serial_enum_ln("Failed attempt " + String(attempt) + ". New attempt ...");
                    attempt++;
                    /*
                        The following delay causes about 65mAh of 
                        power loss. A better solution is required!
                        Maybe a oneshot without re-attempts?
                    */
                    delay(1000);
                }
                break;
        }
    }

    String server_answer = http.getString();
	http.end();

    serial_info("Server answer: ");
    serial_print_ln(server_answer);

    DynamicJsonDocument json_doc_root(1024);
    deserializeJson(json_doc_root, server_answer);
    JsonObject j_root = json_doc_root.as<JsonObject>();

    /*
        Firmware update can't be started within the post-function,
        this causes a RAM overflow!
        Current solution: Global variable as trigger.
    */
    firmware.update_needed = j_root["update_firmware"];
    firmware.new_version = j_root["new_firmware"].as<String>();
    filesystem.update_needed = j_root["update_spiffs"];
    filesystem.new_version = j_root["new_spiffs"].as<String>();
}

#pragma endregion DAILY BUSINESS

#pragma region MAIN

void setup()
{       
    serial_init(115200);
    serial_print_ln("\n\nProject Kawa\n");
    serial_info_ln("Firmware " + String(firmware_version));
    serial_info_ln("SPIFFS   " + String(filesystem_version));

    serial_info_ln("Setting up IO...");
    pinMode(out_led, OUTPUT);
    pinMode(btn_1, INPUT_PULLUP);
    pinMode(btn_2, INPUT_PULLUP);
    /*
        Do not set btn_3 as INPUT or INPUT_PULLUP when onewire
        is in use. It's the same input and causes the onewire bus to fail.
    */
    // pinMode(btn_3, INPUT_PULLUP);
    digitalWrite(out_led, OFF);

    serial_info_ln("Setting up file system...");
    SPIFFS.begin();
    delay(100);

    serial_info_ln("Reading controller data...");
    get_voltage();

    serial_info_ln("Reading config file...");
    read_config();
    
    if (!digitalRead(btn_1))
    {
        serial_warning_ln("Button 1 was pressed during boot.");
        launch_ap();
    }
    else if (!digitalRead(btn_2))
    {
        serial_warning_ln("Button 2 was pressed during boot.");
        clear_config();
        digitalWrite(out_led, ON);
        delay(3000);
        digitalWrite(out_led, OFF);
        ESP.restart();
    }
    else if (connect_wifi())
    {
        sensor_ok = init_sensor();
        if (sensor_ok)
            get_sensor_data();
        
        post_data();
        unsigned long took = millis() - startup_time;
        serial_info_ln("Time since boot: " + String(took) + "ms.");

        if (firmware.update_needed)
            update_firmware(firmware.new_version);
        if (filesystem.update_needed)
            update_filesystem(filesystem.new_version);
    }
    else
    {
        /*
            Indicate that the WiFi isn't setup properly.
        */
       blink(25);
    }

    if (voltage.value < battery_too_low)
        enter_deep_sleep_max();
    else
        enter_deep_sleep(cfg.interval);
}

void loop() 
{
    /*
        Nothing to do here.
    */
    serial_warning_ln("This should not be possible!");
    delay(1000);
}

#pragma endregion MAIN

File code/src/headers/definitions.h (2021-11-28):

/*
    Project Kawa Client | DEFINITIONS

    Date        2021.07.11
    Author      Philip Delorenzo
    License     None
    Repo        https://github.com/deloarts/project-kawa-devboard

*/

#define board_name "devboard"
#define firmware_version "0.1.2"
#define filesystem_version "0.1.0"

/*
    If mode is set to DEBUG, don't forget to add the 'd' to the
    firmware-version when building the final binary.
*/
#define DEBUG
#ifdef DEBUG
    #define software_state "debug"

    #define serial_init(x) Serial.begin(x)

    #define serial_print(x) Serial.print(x)
    #define serial_info(x) Serial.print("[INFO]\t\t" + String(x))
    #define serial_warning(x) Serial.print("[WARNING]\t" + String(x))
    #define serial_error(x) Serial.print("[ERROR]\t\t" + String(x))
    #define serial_blank(x) Serial.print("\t\t\t" + String(x))
    #define serial_enum(x) Serial.print("\t\t\t - " + String(x))

    #define serial_print_ln(x) Serial.println(x)
    #define serial_info_ln(x) Serial.println("[INFO]\t\t" + String(x))
    #define serial_warning_ln(x) Serial.println("[WARNING]\t" + String(x))
    #define serial_error_ln(x) Serial.println("[ERROR]\t\t" + String(x))
    #define serial_blank_ln(x) Serial.println("\t\t\t" + String(x))
    #define serial_enum_ln(x) Serial.println("\t\t\t - " + String(x))

    #define serial_print_hex(x) Serial.print(x, 16)
    #define serial_print_hex_ln(x) Serial.println(x, 16)
#else
    #define software_state "production"

    #define serial_init(x)

    #define serial_print(x)
    #define serial_info(x)
    #define serial_warning(x)
    #define serial_error(x)
    #define serial_blank(x)
    #define serial_enum(x)

    #define serial_print_ln(x)
    #define serial_info_ln(x)
    #define serial_warning_ln(x)
    #define serial_error_ln(x)
    #define serial_blank_ln(x)
    #define serial_enum_ln(x)

    #define serial_print_hex(x)
    #define serial_print_hex_ln(x)
#endif

#define ON 0x0
#define OFF 0x1

#define i2c_address 0x76
#define i2c_sda 5
#define i2c_scl 4

#define btn_1 12
#define btn_2 13
// #define btn_3 14
#define btn_reset 16
#define btn_upload 0
#define out_led 2
#define ONE_WIRE_BUS 14

// Power & deep sleep
#define battery_available true
#define battery_full 3.4
#define battery_too_low 3.29
#define default_sleep_interval 60 //minutes

// Units
#define unit_interval "s"
#define unit_connection "ms"
#define unit_voltage "V"
#define unit_temperature "°C"
#define unit_pressure "mBar"
#define unit_altitude "m"
#define unit_humidity "%"

// Sensor types
#define type_na "N/A"
#define type_bme280 "BME280"
#define type_ds18b20 "DS18B20"

// Sensor corrections
#define altitude_p0 1013.25

// Server API
#define api_post_data "/api/data"
#define api_get_update "/api/updates"

// Internal API
#define api_get_config "/get"
#define api_post_config "/post"
#define api_restart "/restart"
#define api_reset "/reset"

#define max_retries_wifi 100
#define max_retries_post 5

#define device_hostname_prefix "kawa_"

#define hotspot_hostname "kawa"
#define hotspot_ssid "kawa setup"
#define hotspot_password ""
#define hotspot_ip 1,2,3,4
#define hotspot_gateway 1,2,3,4
#define hotspot_subnet 255,255,255,0
#define hotspot_dns_port 53

// Files
#define spiffs_config_file "config.json"

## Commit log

2021-07-12 added cad files
    [100nF 50V.CATPart, 10uF 100V.CATPart, 1X02_90.CATPart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]
2021-09-10 added location as device parameter
2021-09-11 added bill of material and pdf schematics
2021-09-14 updated battery range
2021-11-21 updated housing
    [100nF 50V.CATPart, 10uF 100V.CATPart, 1X02_90.CATPart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]
2023-08-27 Public Repo
    [Project Kawa Devboard.xls]

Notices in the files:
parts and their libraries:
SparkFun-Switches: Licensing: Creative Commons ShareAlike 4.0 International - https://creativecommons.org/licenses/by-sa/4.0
